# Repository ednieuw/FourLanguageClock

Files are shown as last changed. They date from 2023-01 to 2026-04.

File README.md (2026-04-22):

<h1>&nbsp;SK6812 Four languages word clock</h1>
<p>With this clock time can be displayed as text in the languages Dutch, 
French, English and German.<br>
This clock was the ultimate challenge to make 
with its predecessor a single language word clock and Fibonacci clocks.<br>
	The software to control the clock is written for Arduino with a minimum memory of 
48K such as the cheap Arduino Nano Every.<br>
	
(Update Apr 2026) For the Arduino Nano ESP32 use ESP32_WordclockV202 from this repository.<br>
[For the manual and latest versions see here](https://github.com/ednieuw/Arduino-ESP32-Nano-Wordclock)
	
In addition to controlling the correct time, there are many options that can be set in the program.<br>For 
example, a single language for a clock with 144 (12x12) LEDs, various membrane 
keypads, a rotary, digital displays, a DCF77 atomic time receiver, Bluetooth 
connection to a mobile phone, and support for SK6812 and other LED strips.</p>
<p >&nbsp;</p>
<table>
  <tr><td><a href="4LanguageClock/IMG_5557.JPG">
	<img src="4LanguageClock/IMG_5557k.JPG" alt="Four language clock color" "></a></td><td>
	<a href="4LanguageClock/IMG_5560.JPG">
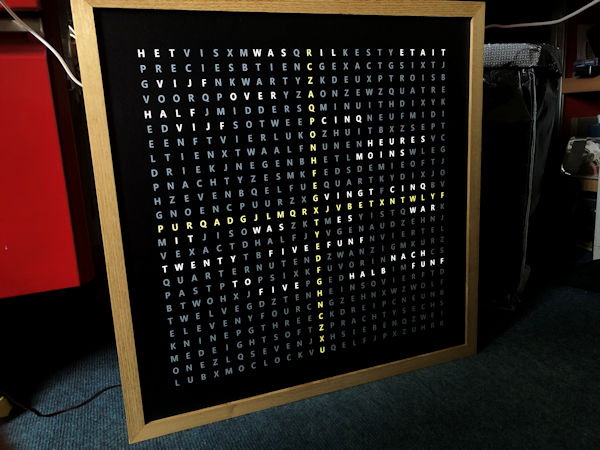
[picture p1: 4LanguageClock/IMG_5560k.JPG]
Four language clock white
	</a></td>
</tr><tr><td>
<br>
<p>&nbsp;</p>
<p>The four-language word clock uses 625 SK6812 RGBW LED strips.<br>RGBW 
LED strips have a white LED in addition to the red, green and blue LED.<br>
This makes it possible to make the letters light up bright white. The 
colors are also sparkling with these SK6812 LEDs.<br>The library used to 
drive the LEDs also supports the use of many types of other LEDs.<br>
<br><br>SK6812 LEDs each contain a small processor, which means that the 
entire chain of LEDs can be controlled with one wire.</p>
</td><td><div align="left">
<a href="4LanguageClock/4-talenklok_IMG_1176.jpg">
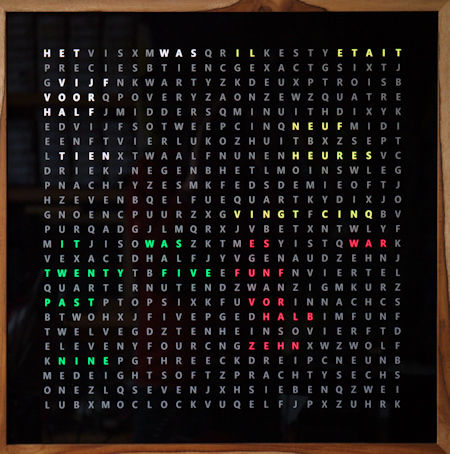
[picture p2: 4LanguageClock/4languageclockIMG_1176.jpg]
Word clock with four languages
</a></div></td></tr>
</table>
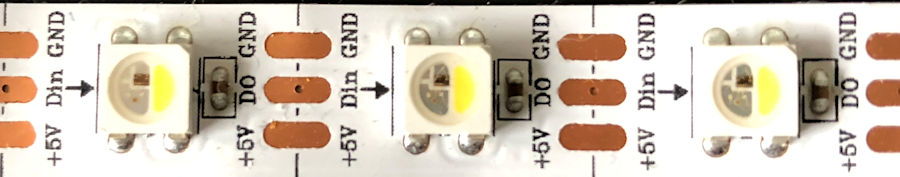
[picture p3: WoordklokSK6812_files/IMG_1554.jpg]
<p>&nbsp;&lt;- <a href="https://ednieuw.nl/Woordklok/index.html">Overview home page<br></a><br><br>
<br>

<br ><span><strong>Accessories</strong></span><br>
The color word clock consists of the parts as shown in the table below.<br>
<table cellspacing="0">
  <tr>
    <td class="xl67" width="277">1 x case for 50x50 cm word plate </td>
    <td class="xl74" width="136">kast </td>
  </tr>
  <tr>
    <td class="xl70">1 x word plate <br>
      JPG-file with:<br>
<a href="4LanguageClock/Viertalen-AlleLetters-23okt2018_50x50cm.jpg">All 625 characters</a><br>
	      <br>
          <a href="4LanguageClock/Viertalen-23okt2018_50x50cm.jpg">With a cross</a></td>
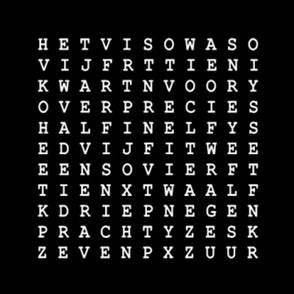
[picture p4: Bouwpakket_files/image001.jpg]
woordplaat
    <td class="xl75">  </td>
  </tr>
  <tr>
    <td class="xl71">1 x Spacerplaat, foamed PVC wit 10 MM RAL 9003</td>
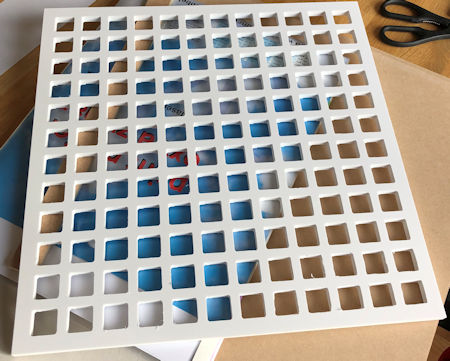
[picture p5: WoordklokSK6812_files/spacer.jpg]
spacerplaat
    <td class="xl76"> </td>
  </tr>
  <tr>
    <td class="xl70">1 x PCB SK6812-klok </td>
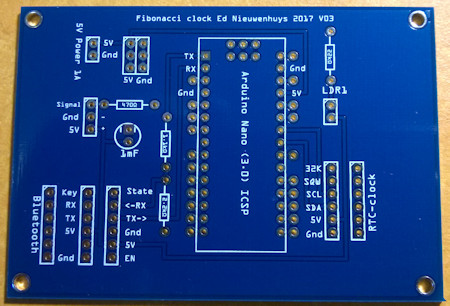
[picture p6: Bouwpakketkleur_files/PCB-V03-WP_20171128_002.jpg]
PCB
    <td class="xl75"> </td>
  </tr>
  <tr>
    <td class="xl70">1 x 1000 µF capacitor </td>
    <td class="xl75">1000 µF condensator </td>
  </tr>
  <tr>
    <td class="xl70">1 x 1.1kΩ resistor </td>
    <td class="xl75">&nbsp; </td>
  </tr>
  <tr>
    <td class="xl70">1 x 2.2kΩ resistor </td>
    <td class="xl75">&nbsp; </td>
  </tr>
  <tr>
    <td class="xl70">1 x 470kΩ resistor (1-3 needed) </td>
    <td class="xl75">470O weerstand </td>
  </tr>
  <tr>
    <td class="xl70">1 x LED red </td>
    <td class="xl75"> </td>
  </tr>
  <tr>
    <td class="xl70">1 x LED yellow </td>
    <td class="xl75"> </td>
  </tr>
  <tr>
    <td class="xl70">1 x 2-pin female connector </td>
    <td class="xl75">&nbsp; </td>
  </tr>
  <tr>
    <td class="xl70">1 x 3-pin female connector </td>
    <td class="xl75">&nbsp; </td>
  </tr>
  <tr>
    <td class="xl70">1 x 5-pin female connector </td>
    <td class="xl75">&nbsp; </td>
  </tr>
  <tr>
    <td class="xl70">2 x 6-pin female connector </td>
    <td class="xl75">&nbsp; </td>
  </tr>
  <tr>
    <td class="xl70">2 x 15-pin female connector </td>
    <td class="xl75">&nbsp; </td>
  </tr>
  <tr>
    <td class="xl70">1 x Arduino Nano Every </td>
    <td class="xl75">&nbsp; </td>
  </tr>
  <tr>
    <td class="xl70">1 x SK6812 LED-strip 625 LEDs </td>
    <td class="xl75">WS2812 </td>
  </tr>
  <tr>
    <td class="xl67">1 x&nbsp; KY-040 Keyes Rotary Encoder </td>
    <td class="xl74">KY-040 Keyes Rotary Encoder </td>
  </tr>
  <tr>
    <td class="xl70">1 x 4x3 membrane keypad </td>
    <td class="xl75">
      <p>&nbsp;</p>
      <p>&nbsp;</p>
      <p>&nbsp;</p></td>
  </tr>
  <tr>
    <td class="xl70">1 x RCT DS3231 clock module <br>
      ZS-042 </td>
    <td class="xl75">DS3231 </td>
  </tr>
  <tr>
    <td class="xl70">1 x CR 2032 3V lithium battery </td>
    <td class="xl75">Batterij </td>
  </tr>
  <tr>
    <td class="xl70">1 x light sensor </td>
    <td class="xl75">Lichtsensor </td>
  </tr>
  <tr>
    <td class="xl71">1 x 22kΩ resistor </td>
    <td class="xl76">22kO weerstand </td>
  </tr>
  <tr>
    <td class="xl70">1 x Adapter 5V DC, &gt;2 Ampere </td>
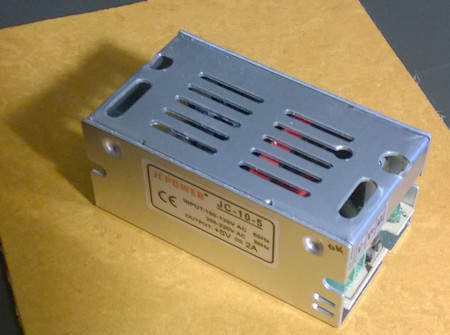
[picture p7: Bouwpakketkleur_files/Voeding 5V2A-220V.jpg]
Voeding220V
    <td class="xl75"> </td>
  </tr>
  <tr>
    <td class="xl67">1 x Verlichtingsgrondplaat 3 x 300 x 300 mm MDF-plaat </td>
    <td class="xl74">&nbsp; </td>
  </tr>
  <tr>
    <td class="xl70">1 x Adapter 5V DC, &gt;2 Ampere </td>
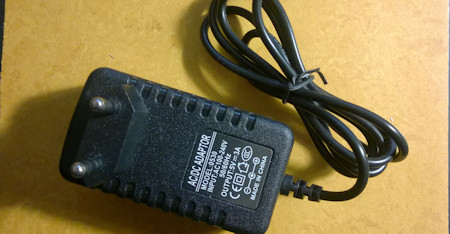
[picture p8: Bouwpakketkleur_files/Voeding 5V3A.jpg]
Voeding
    <td class="xl91"> </td>
  </tr>
  <tr>
    <td class="xl67">Wireless Serial 6 Pin Bluetooth RF Transceiver Module HM10 (voor Iphone, IPad) </td>
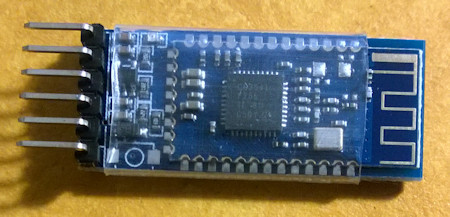
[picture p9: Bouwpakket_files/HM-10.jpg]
HM10 BT
    <td class="xl74"> </td>
  </tr>
</table>
<p class="auto-style3"><strong><br class="auto-style3">
    Assembling the lighting base plate <br class="auto-style3">
  <br class="auto-style3">
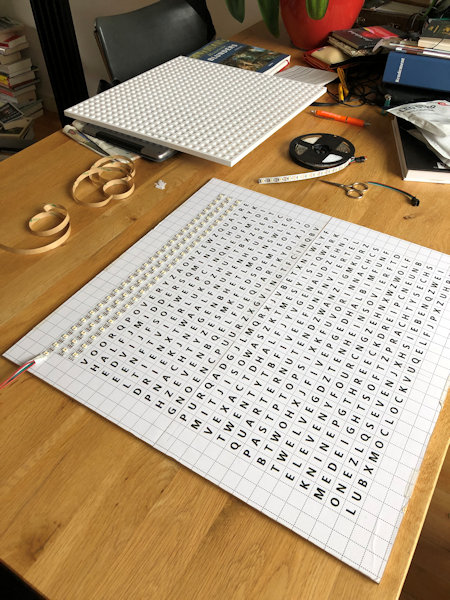
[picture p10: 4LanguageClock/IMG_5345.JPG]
Verlichtings grondplaat
  <br class="auto-style3">
</strong><br class="auto-style3">
</p>
<p>The distance between the LEDs on the strip is suitable to make a clock of 50 
x 50 cm (60 LEDs/m).<br>You can choose to stick the 625 LEDs of the clock in 25 
rows with 25 LEDs or only LEDs behind the letters that should light up.<br>The 
latter method has the advantage that fewer LEDs are needed and that you have to 
drill fewer holes in the spacer plate. But .. there are many more soldering 
points, each of which can cause malfunctions.<br>The software also has a digital 
time mode mode that you can only use if you install all 625 LEDs.<br><br>You can also 
choose to cut out the illuminated words in a 1 cm thick MDF board with a jigsaw.<br>
Paint the insides white otherwise the white light will become dingy.<br>Stick 
the strips from left to right on the odd lines and from right to left on the 
even lines. Follow the arrows on the strip.<span class="auto-style3"><br></p>
<p>Apply solder to the LED strip terminal and later solder the wire in the 
solder blob.<br>A reasonable amount of current (1A) will flow at full 
load. If you are going to connect all the strips in succession, a lot of current 
will flow at the first LEDs and the wire must be thick.<br>I make a connection 
per two lines from the power wire with 30AWG = 0.25mm diameter.<br>30AWG wire 
can tolerate 0.9A current<br>or not insulated tinned copper wire of 0.6mm on one 
side of the strips the 5V connection and on the other side the earth connection.<br>
Finally, make sure that each strip has its power.<br>The spacer plate will be 
placed on the front, on top of the LEDs, and it must lie flat on the surface to 
prevent light leakage.</p>
<table><tr><font face="Verdana, Arial, Helvetica, sans-serif"><td>
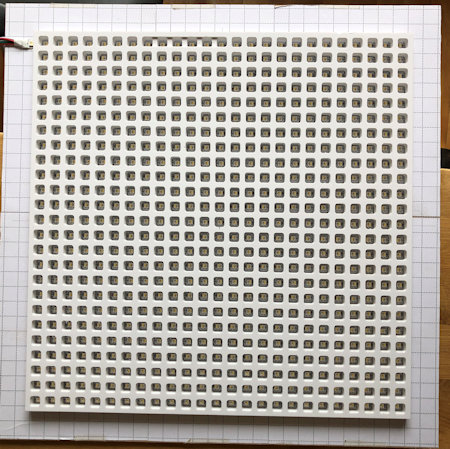
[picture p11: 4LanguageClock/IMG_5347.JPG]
Spacerplaat
 </td>
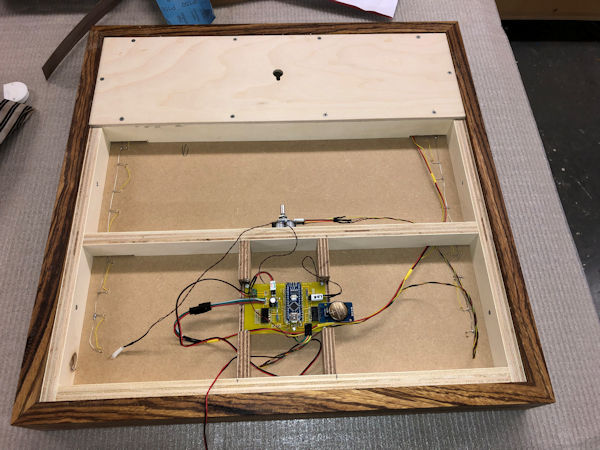
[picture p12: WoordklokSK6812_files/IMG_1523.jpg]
<td></td> 
</font></tr><tr><td>spacer plate</td><td">
Back side</td></tr></table><br">
<p>In the signal wire between LED_PIN 5 (D5) of the Arduino and the SK6812 LED 
connection Di is a 470 Ohm resistor.<br>A 1 mF (1000 uF) capacitor is placed 
across the GND and 5V to the LED strip to dampen the turn-on voltage.<br>The 
LEDs do work without these two components (onrush preventer) but can be damaged.<br>
The onrush preventer schedule is below.<br>You can connect all components 
directly to the pins of the Arduino Nano without the printed circuit board.<br>
There is also a PCB to which everything can be soldered.<br>This printed circuit 
board can also be used for the <a href="https://github.com/ednieuw/Fibonacciclock">Fibonacci clock</a>.<br>
</p>
<p>At the bottom of this page 
the latest PCB version with more connections.</p>
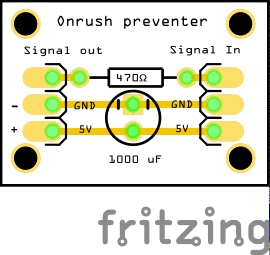
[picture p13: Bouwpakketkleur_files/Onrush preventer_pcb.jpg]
Onrush
<table><tr><td></td>
<td>PCB V03</td>
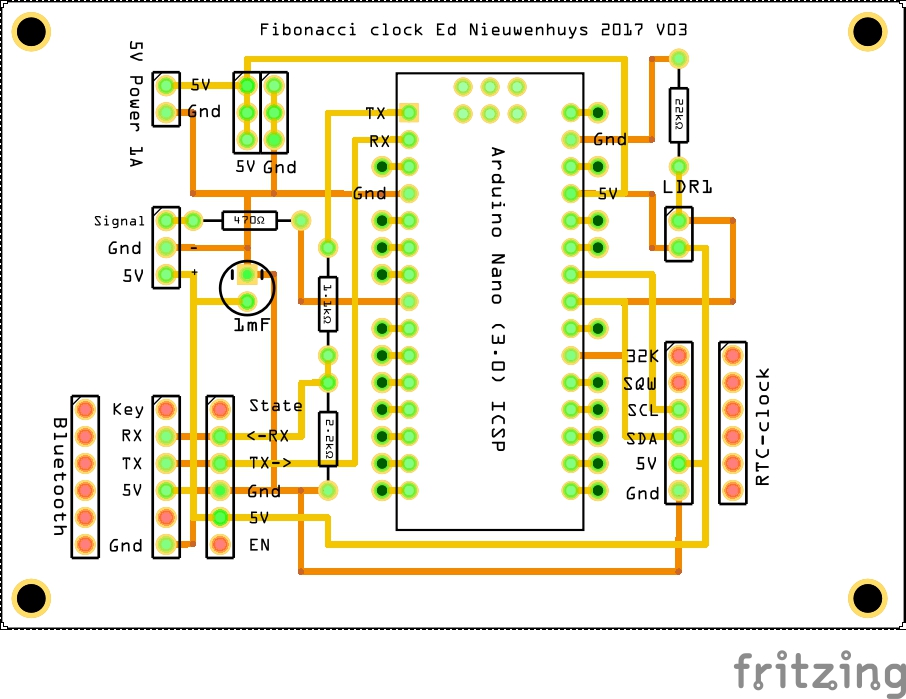
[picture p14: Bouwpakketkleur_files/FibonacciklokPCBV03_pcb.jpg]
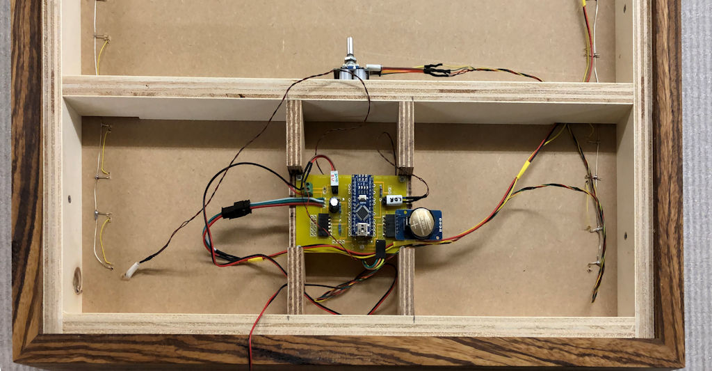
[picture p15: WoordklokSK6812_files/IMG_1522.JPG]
</tr><tr><td colspan="2"><br class="auto-style3"></td></tr><tr><td colspan="2"></td>
</tr><tr><td>
	Connections in the case</td><td class="auto-style3">&nbsp;
	</td></tr></table><span class="style1"><br>// digitale port connections on Arduino&nbsp; D2 - D13<br>
	</span>
<pre>enum DigitalPinAssignments {      // Digital hardware constants ATMEGA 328 ----
 RX           = 0,                // Connects to Bluetooth TX
 TX           = 1,                // Connects to Bluetooth RX
 DCF_PIN      = 2,                // DCFPulse on interrupt  pin
 encoderPinA  = 3,                // right (labeled DT on decoder)on interrupt  pin
 clearButton  = 4,                // switch (labeled SW on decoder)
 LED_PIN      = 5,                // Pin to control colour SK6812/WS2812 LEDs
 BT_TX        = 6,                // Connects to Bluetooth RX
 BT_RX        = 7,                // Connects to Bluetooth TX
 HC_12TX      = 6,                // HC-12 TX Pin  // note RX and TX are reversed compared with a BT Module
 HC_12RX      = 7,                // HC-12 RX Pin 
 encoderPinB  = 8,                // left (labeled CLK on decoder)no interrupt pin  
 secondsPin   = 9,
 HeartbeatLED = 10,               // PIN10        = 10,                        // PIN 10 
 DCFgood      = 11,               // DCF-signal &gt; 50    //PIN11        = 11,   // PIN 11
 PIN12        = 12,               // PIN 12             // led = 12,          // MKR1010
 DCF_LED_Pin  = 13,               // DCF signal
 };
 
enum AnaloguePinAssignments {     // Analogue hardware constants ----
 EmptyA0      = 0,                // Empty
 EmptyA1      = 1,                // Empty
 PhotoCellPin = 2,                // LDR pin
 EmptyA3      = 3,                // Empty
 SDA_pin      = 4,                // SDA pin
 SCL_pin      = 5,                // SCL pin
 EmptyA6     =  6,                // Empty
 EmptyA7     =  7};               // Empty</pre>
<span class="style2">&nbsp;</span><p><strong>Assembling the clock</strong><br>
<br>It is convenient to tape the clock parts with paper masking tape. This 
adhesive tape comes off easily.<br>Stick the lighting plate and spacer together.<br>
Stick a white sheet of paper over the spacer. Paper gives a nice drawing to the 
illuminated letters.<br>Place the word plate over the paper and fix it with 
adhesive tape as well.<br>With a hardwood clock, depending on the version, the 
word plate is slid into the slot in the cabinet. Then assemble the fourth, 
bottom part of the cabinet.<br>Glue this or stick it temporarily with adhesive 
tape.<br>If everything is labeled correctly, the clock, rotary encoder, LDR, 
power supply can be connected.<br>Assemble the cabinet.</p>
<p><br><br></p>
<p><strong>Bluetooth connection</strong><br><br>A Bluetooth connection to the clock can be made 
with the HC05 or HM-10 Bluetooth module.<br>The HC05 only communicates with 
Android. The HM-10 communicates with both Android and Apple IOS.<br>The link 
below describes to which pins the module is connected and how the name of the 
module is changed.<br>With a Bluetooth terminal app on the phone, the time can 
be sent to the clock as hhmmss or hhmm.<br>The clock sends data back to the 
terminal app every minute.<br>Bluetooth terminal apps are available for Windows 
phone, Android and 
<a href="https://apps.apple.com/tt/app/bleserial-hm-10/id1602239700#?platform=iphone">
IPhone</a>.<br>The Bluetooth terminal programs are also available 
for PCs.<br>The Bluetooth module communicates between RX (read) and TX 
(transmit) at 3.3V.<br>It is possible to connect it directly to the Arduino 
ports but it will extend the life of the module if the voltage is lowered to 
3.3V.<br>This can be done with a 3.3V-5V TTL Level Logic Level Converter module, 
or with a voltage divider circuit with resistors as shown below.<br>You can also 
mount the resistors in the wiring from the module to the printed circuit board.</p>
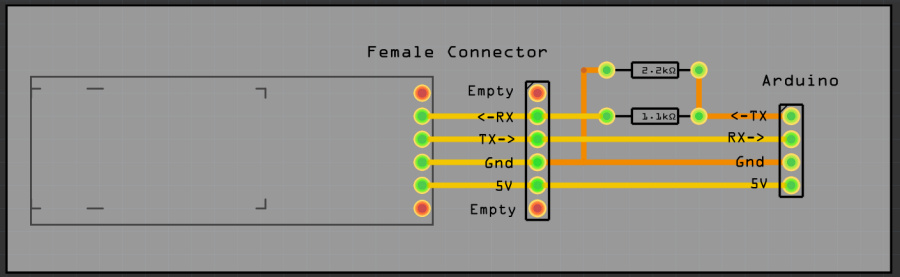
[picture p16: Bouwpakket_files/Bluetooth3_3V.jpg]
Schema BT
<p><font class="auto-style3"><br><br><br>
</font><br></p>
<p><strong>Bluetooth with the HM10 BLE for Android and Apple IOS</strong><br>
With this HM10 BLE module you can communicate with Apple IOS and Android.<br>After that, commands can be sent 
with a serial terminal program (<a href="https://apps.apple.com/tt/app/bleserial-hm-10/id1602239700#?platform=iphone">BLEserial HM-10 for IOS 
</a>or for Android BLE 
scanner from Blue Pixel Technologies) and the clock output can be collected.<br>
<br>Linked via an FTDI, AT commands can be given with the Arduino serial monitor 
with the Bluetooth module.<br>See previous section for AT commands<br>
AT+NAMEnewname gives the module the name: newname</p>
<p><a href="https://ednieuw.nl/BLESerial/BLESerialUsage.html">More info about Bluetooth 
communication on this page</a></p>
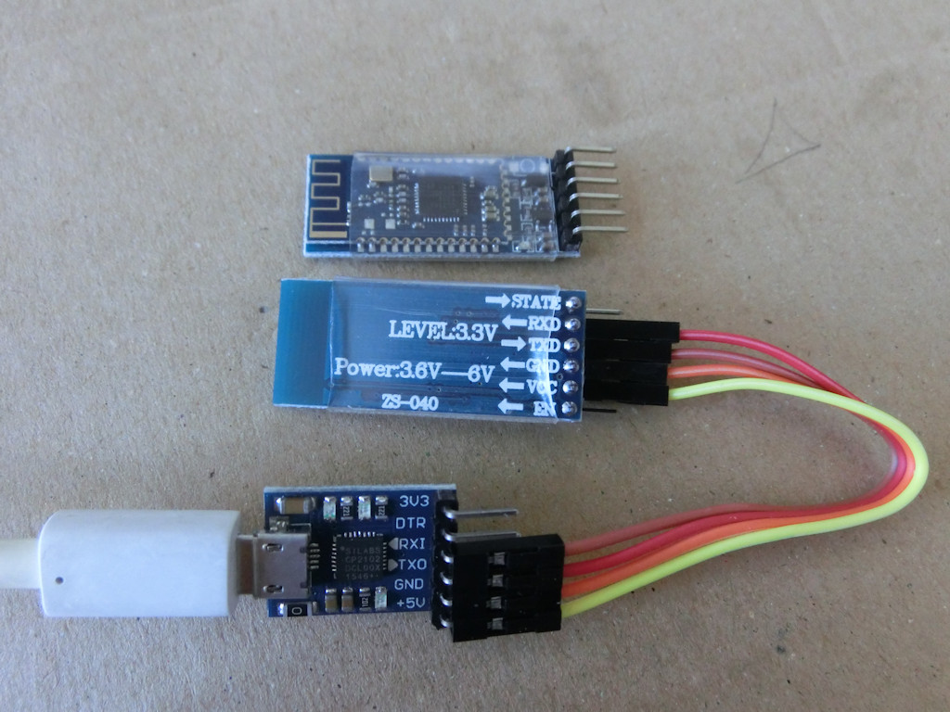
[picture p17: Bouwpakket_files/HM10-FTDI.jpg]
HM-10 BT
<p><font><br><br>
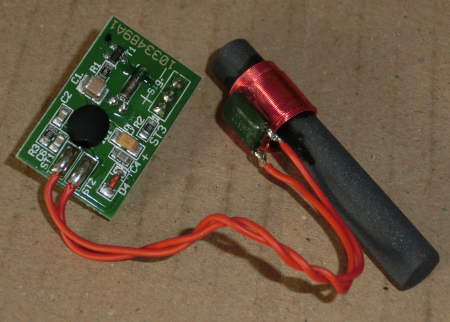
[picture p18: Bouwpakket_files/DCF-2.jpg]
DCF-2
<br><strong>DCF77-ontvangst met DCF-2 module </strong><br><br><br>
</font></p>
<p>Unfortunately, the ICs in the color LEDs interfere with DCF reception. With 
the SK6812 LEDs the interference seems less than with WS2812 color LEDs.<br>With 
these color LEDs, the DCF receiver module must be mounted 10 cm or more from the 
LEDs.<br>The latest software versions V058 and above combine two reception 
methods;<br>the Arduino standard DCF77 library and an interrupt free method 
written by me.<br>I have combined them in the software, which increases 
efficiency by more than 50% in the event of poor reception.<br>Of the 44,000 
minute receptions, with the ferrite rod hanging 7cm from WS2812 color LEDs, 
13,000 were properly processed to a time and date by the DCF77 library and 
22,000 by the interrupt-free routine.<br>This DCF77 module has three 
connections; +, - and signal.<br>Connect the + to 5V and the - to GND.<br>Signal 
goes to pin 2.<br>NB Pin 2 was used for the rotary encoderPinB left (labeled CLK 
on decoder). This is now connected to P8.<br>(Pin 2 is an interrupt pin. For 
optimal DCF reception, responding to an interrupt is not necessary for the 
rotary encoder.<br>Look in the source of the version of the software under "PIN 
Assigments" for the correct connection.</p>
<p><font class="auto-style3"><br><a href="https://ednieuw.nl/Woordklok/DCF77/DCF77_Arduino.html">Here some 
background information DCF</a></font></p>
<p>&nbsp;</p>
<p class="auto-style3"><a href="Libraries-needed-for-ColourClock.zip">Libraries needed</a> 
in this zip-file the needed libraries.<br>
</p><p class="auto-style3"><strong>Software<br></strong></p>
<p>The libraries used can be found in the Arduino IDE.<br>If that is no longer 
the case, the urls to the library have been put below</p>
<pre>
#include "RTClib.h"              // https://github.com/adafruit/RTClib 
#include &lt;TimeLib.h&gt;             // For time management 
#include &lt;Adafruit_NeoPixel.h&gt;   // https://github.com/adafruit/Adafruit_NeoPixel 
#include &lt;SoftwareSerial.h&gt;      // For Bluetooth
#include &lt;Encoder.h&gt;             // http://www.pjrc.com/teensy/td_libs_Encoder.html                      
#include "DCF77.h"               // http://playground.arduino.cc/Code/DCF77 </pre>
<p class="auto-style2"><font class="auto-style3">
<strong>PCB V14</strong><br></font>The latest PCB versions
<span class="auto-style3"> 
<a href="WoordklokSK6812_files/Colour%20Word%20Clock%20PCBV14.fzz">V14</a>
</span>&nbsp;of the PCB have fixed connections for the most commonly used parts.<br>
It is now possible to choose whether the serial connection to the Bluetooth 
module is via the standard connections<br>0 and 1, TX and RX, or whether it goes 
through terminals D6 and D7.<br>In the current version, D6 and D7 are used for 
the Bluetooth module and the pads at D6 and D7 must be soldered closed.<br>The 
signal wire in V14 to the LEDs has been moved relative to V13 so that the 
position of the connections corresponds to the LED strip.</p>
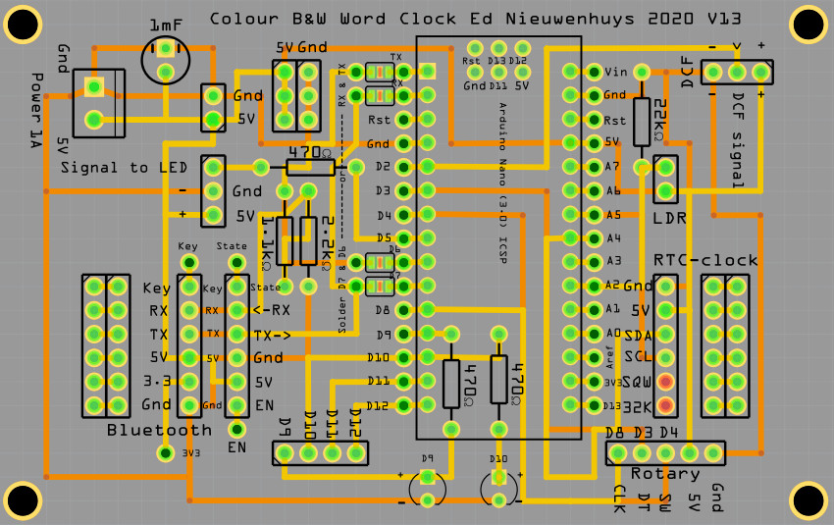
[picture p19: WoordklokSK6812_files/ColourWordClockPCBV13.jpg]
PCB versie V14
<br>&nbsp;<br>
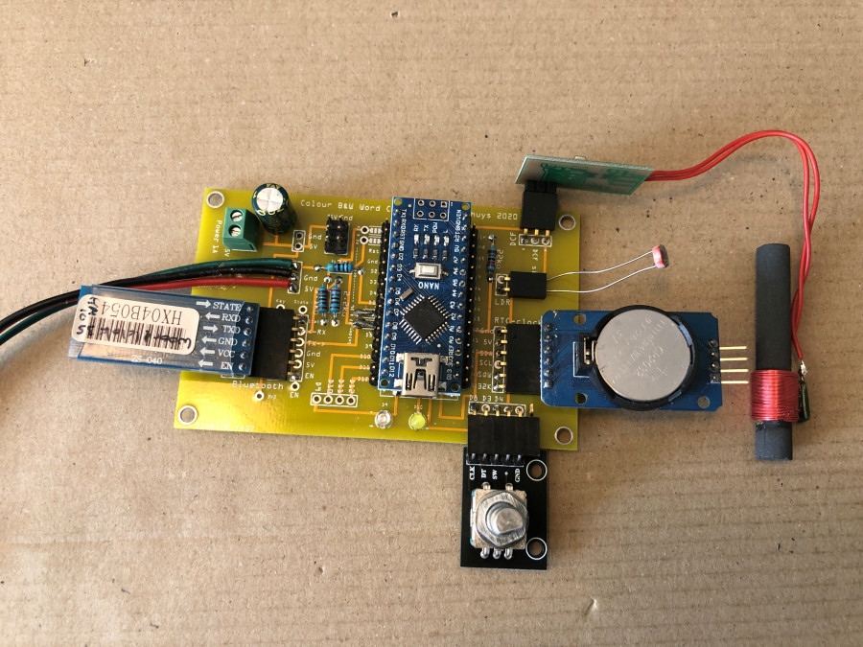
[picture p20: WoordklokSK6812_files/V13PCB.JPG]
PCB V13
<br>
<br class="auto-style3">
<p class="auto-style2"><font class="auto-style3">
</font></p>

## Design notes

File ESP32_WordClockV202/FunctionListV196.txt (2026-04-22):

void setup()                                                                                // ARDUINO Setup.
void loop()                                                                                 // ARDUINO Loop.
void CheckDevices(void)                                                                     // COMMON Check connected input devices.
void EverySecondCheck(void)                                                                 // COMMON Update routine.
void Every100mSecCheck(void)                                                                // COMMON Update routine.
void EveryMinuteUpdate(void)                                                                // COMMON Update routine done every minute.
void EveryHourUpdate(void)                                                                  // COMMON Update routine done every hour.
void EveryDayUpdate(void)                                                                   // COMMON Update routine done every day.
void UpdateStatusLEDs(bool Toggle)                                                          // COMMON Update routine for the status LEDs.
void SetStatusLED(int Red, int Green, int Blue)                                             // COMMON Control the RGB LEDs on the Nano ESP32.
void SetNanoLED13(int intensity)                                                            // COMMON Control orange LED D13 on the Arduino.
void SetPCBLED09(int intensity)                                                             // COMMON Control the RGB LED on the PCB.
void SetPCBLED10(int intensity)                                                             // COMMON Control the RGB LED on the PCB.
void SerialCheck(void)                                                                      // COMMON check for serial input.
void Reset(void)                                                                            // COMMON Reset to default settings. BLE On, WIFI NTP Off.
void ResetCredentials(void)                                                                 // COMMON Reset to empty credential settings WIFI, NTP, BLE ON.
void Tekstprint(char const *tekst)                                                          // COMMON common print routines.
void Tekstprintln(char const *tekst)                                                        // COMMON common print routines.
void TekstSprint(char const *tekst)                                                         // COMMON common print routines.
void TekstSprintln(char const *tekst)                                                       // COMMON common print routines.
void Tekstprintf(const char* fmt, ...)                                                      // COMMON Formatted Tekst print.
void Tekstprintlnf(const char* fmt, ...)                                                    // COMMON Formatted Tekstprintln.
void WTekstappend(char const *tekst, char const *prefix, char const *suffix, bool newline)  // COMMON Print web menu page and BLE menu.
void WTekstprintln(char const *tekst)                                                       // COMMON Print web menu page and BLE menu.
void WTekstprintln(char const *tekst, char const *prefix, char const *suffix)               // COMMON Print web menu page and BLE menu.
void WTekstprint(char const *tekst)                                                         // COMMON Print web menu page and BLE menu.
void WTekstprint(char const *tekst, char const *prefix, char const *suffix)                 // COMMON Print web menu page and BLE menu.
int SConstrainInt(String s,byte first,byte last,int low,int up)                             // COMMON Constrain a string with integers.
int SConstrainInt(String s,byte first,          int low,int up)                             // COMMON Constrain a string with integers.
void InitStorage(void)                                                                      // COMMON Init and check contents of EEPROM.
void StoreStructInFlashMemory(void)                                                         // COMMON Store mem.struct in FlashStorage or SD.
void StoreIRRemoteInFlashMemory(void)                                                       // COMMON Save IR remote settings.
void GetStructFromFlashMemory(void)                                                         // COMMON Get data from FlashStorage.
void GetIRRemoteFromFlashMemory(void)                                                       // COMMON Load IR remote settings from FlashStorage.
void SWversion(void)                                                                        // COMMON Version info.
void SWversion(bool Small)                                                                  // COMMON Version info.
void PrintLine(byte Lengte)                                                                 // COMMON Print a _ line of n length.
void ReworkInputString(String InputString)                                                  // COMMON Input from Bluetooth, Serial or HTML page.
void PrintDisplayChoice()                                                                   // COMMON Print Display choice.
void PrintDisplayChoice(bool PrintIt)                                                       // COMMON Print Display choice.
void PrintTimeInputMethod(byte Im)                                                          // COMMON Print time input method.
void PrintMem(void)                                                                         // COMMON Print permanent Mem memory.
void StoredStartHeaps()                                                                     // COMMON Print memory space.
void StoredStartHeaps(bool Store)                                                           // COMMON Print memory space.
void PrintHeaps(void)                                                                       // COMMON Print memory space.
int ReadLDR(void)                                                                           // COMMON LDR reading are between 0 and 255.
void SetSecondColour(void)                                                                  // CLOCK Set second colour.
void SetColours(void)                                                                       // CLOCK Set second for 4 language clock.
void Selftest(void)                                                                         // CLOCK Set second for 4 language clock.
void Selftest(int Delayms)                                                                  // CLOCK Set second for 4 language clock.
void Displaytime(void)                                                                      // CLOCK Say the time and load the LEDs.
void DimLeds(bool print)                                                                    // CLOCK Dim the leds measured by the LDR and print values.
void Play_Lights()                                                                          // CLOCK Turn On en Off the LED's.
void BlinkUUR(int NoofBlinks, int Delayms)                                                  // CLOCK Turn On en Off the LED's.
void BlinkHETISWAS (int NoofBlinks, int Delayms)                                            // CLOCK Blink ES IST WAR.
void BlinkTWAALF(int NoofBlinks, int Delayms)                                               // CLOCK Blink ZWOLF.
void BlinkUUR(int NoofBlinks, int Delayms)                                                  // CLOCK Blink UUR.
void BlinkHETISWAS (int NoofBlinks, int Delayms)                                            // CLOCK Blink HET IS WAS.
void BlinkTWAALF(int NoofBlinks, int Delayms)                                               // CLOCK Blink TWAALF.
void ColorLeds(char const *Tekst, int FirstLed, int LastLed, uint32_t RGBWColor)            // LED Set color for LEDs in strip and print tekst.
void ColorLed(int Lednr, uint32_t RGBWColor)                                                // LED Set color for LEDs in strip and print tekst.
void LedsOff(void)                                                                          // LED Clear display settings of the LEDs.
void Laatzien(int Delaymsec)                                                                // LED Turn On and the LEDs off after Delaymsec milliseconds.
void ShowLeds(void)                                                                         // LED Push data in LED strip to commit the changes.
void SetBrightnessLeds(byte Bright)                                                         // LED Set brighness of LEDs.
void Stripfill(uint32_t RGBWColor, int FirstLed, int NoofLEDs)                              // LED Set brighness of LEDs.
uint32_t StripGetPixelColor(int Lednr)                                                      // LED Set brighness of LEDs.
void LEDstartup(uint32_t LEDColour)                                                         // LED Synchronize the colour of the LEDstrip with the Status LED.
uint32_t HSVToRGB(double H, double S, double V)                                             // LED convert HSV to RGB  h is from 0-360, s,v values are 0-1.
uint32_t FuncCRGBW( uint32_t Red, uint32_t Green, uint32_t Blue, uint32_t White)            // LED function to make RGBW colour.
void ClearScreen(void)                                                                      // DISPLAY Clear the display.
uint32_t Wheel(byte WheelPos)                                                               // DISPLAY Wheel The colours are a transition r - g - b - back to r.
void StartLeds(void)                                                                        // DISPLAY Initialyse the LEDstrip for WS2812 or SK6812 LEDs.
void ChangeRandomDisplay(void)                                                              // DISPLAY change display choice.
void RainbowCycle(uint8_t wait)                                                             // DISPLAY RainbowCycle.
void WhiteOverRainbow(uint32_t wait, uint8_t whiteSpeed, uint32_t whiteLength )             // DISPLAY WhiteOverRainbow.
void Zet_Pixel(byte Cijfer,byte Pos_X, byte Pos_Y)                                          // DISPLAY Place digits 0 - 9 in Matrix display.
void TimePlaceDigit(byte uur, byte minuut)                                                  // DISPLAY Time in four digits in display.
void WriteLightReducer(int amount)                                                          // CLOCK In- or decrease light intensity value i.e. Slope.
void InitTimeSystem(void)                                                                   // TIME Initialize time system (DS3231 + NTP + internal RTC).
void SetSystemTimeToCompileTime(void)                                                       // TIME Set system time to compile time using basic functions.
time_t GetTijd(bool printit)                                                                // TIME Get current time from best available source.
DateTime GetLocalDateTime()                                                                 // NTP Return local time as RTClib DateTime.
bool GetNTPtime(bool printit)                                                               // NTP print the NTP time for the timezone set.
bool IsDS3231I2Cconnected(void)                                                             // DS3231 check for I2C connection.
float GetDS3231Temp(void)                                                                   // DS3231 temperature.
void SetDS3231Time(void)                                                                    // DS3231 RTC ESP32 -> DS3231.
void GetDS3231Time(bool printit)                                                            // DS3231 reads time in module DS3231.
void PrintTimeHMS()                                                                         // RTC Fill sptext with time.
void PrintTimeHMS(byte format)                                                              // RTC Fill sptext with time.
void SetRTCTime(void)                                                                       // RTC Set time in ESP32 using global timeinfo struct.
void SetSystemTime(time_t t)                                                                // RTC Set RTC time using Unix timestamp.
void PrintAllClockTimes(void)                                                               // CLOCK Print all the times available.
uint32_t HexToDec(const String& hexString)                                                  // CLOCK Convert Hex to uint32.
void Demomode(void)                                                                         // CLOCK Demo mode.
void FireMode(void)                                                                         // CLOCK Fire display on MATRIX_HEIGHT MATRIX_WIDTH.
uint8_t clamp_sub(uint8_t val, uint8_t sub)                                                 // FIRE Utils.
uint8_t clamp_add(uint8_t val, uint8_t add)                                                 // FIRE Utils.
void HeatColor(uint8_t temperature, uint8_t &r, uint8_t &g, uint8_t &b)                     // FIRE Utils.
uint16_t XY(uint8_t x, uint8_t y)                                                           // FIRE Utils.
void Fire2023_2D()                                                                          // FIRE ==== Fire Logic ====.
void Dutch(void)                                                                            // CLOCK Dutch clock display for NL144 & NL92 clock.
void Dutch(void)                                                                            // CLOCK Dutch clock display for NLM1M2M3M4 clock.
void English(void)                                                                          // CLOCK English clock display.
void German(void)                                                                           // CLOCK German clock display.
void French(void)                                                                           // CLOCK French clock display.
void DitLeHeure(void)                                                                       // CLOCK French clock display.
void SendMessageBLE(std::string Message)                                                    // BLE SendMessage by BLE Slow in packets of 20 chars.
void StartBLEService(void)                                                                  // BLE Start BLE Service.
void DisconnectBLE(void)                                                                    // BLE Disconnect BLE Service.
void CheckBLE(void)                                                                         // BLE CheckBLE input and rework string.
void SendMessageTimeReceiver(const char* msg)                                               // BLE TimeReceiver client.
void ReconnectTimeReceiver()                                                                // BLE TimeReceiver Reconnect time receiver.
void StartTimeReceiverScan(void)                                                            // BLE TimeReceiver Start Time Receiver scan.
void StopTimeReceiver()                                                                     // BLE TimeReceiver Stop Time Receiver.
void CheckTimeReceiverClient(void)                                                          // BLE TimeReceiver Check TimeReceiver Client.
void WiFiEvent(WiFiEvent_t event)                                                           // WIFI WIFIEvents.
void ScanWIFI(void)                                                                         // WIFI Scan for WIFI stations and print a list of networks found.
void ConnectWIFI(void)                                                                      // WIFI Check for WIFI router SSID and password.
void CheckRestoreWIFIconnectivity(void)                                                     // WIFI Check if WIFI is still connected and if not restore it.
bool StartWIFI_NTP(void)                                                                    // WIFI Start WIFI connection and NTP service.
void NTPnotify(struct timeval* tv)                                                          // NTP functions.
void CheckandPrintNTPsynced(void)                                                           // NTP functions.
void setTimezone()                                                                          // NTP functions.
void initSNTP()                                                                             // NTP functions.
bool wait4SNTP()                                                                            // NTP Get a NTP time and wait max 2.5 sec.
void CheckWIFIcommand(void)                                                                 // WIFI Check for a Pending command received from the web page.
void WebPage(void)                                                                          // WIFI WEBPAGE.
void notFound(AsyncWebServerRequest *request)                                               // WIFI WEBPAGE.
void StartAPMode(void)                                                                      // WIFI WEBPAGE Login credentials Access Point page with 192.168.4.1.
void wpsInitConfig()                                                                        // WIFI WPS functions.
void wpsStart()                                                                             // WIFI WPS functions.
void wpsStop()                                                                              // WIFI WPS functions.
String wpspin2string(uint8_t a[])                                                           // WIFI WPS functions.
void OnewireKeypad3x4Check(void)                                                            // KEYPAD check for Onewire Keypad input.
void OnewireKeypad3x1Check(void)                                                            // KEYPAD check for Onewire Keypad input with 5V and 1.1, 4.7, 4.7, 4.7 kOhm resistors.
void Keypad3x1Check(void)                                                                   // KEYPAD 3x1 Init.
void RotaryEncoderCheck(void)                                                               // KY-040 ROTARY check if the rotary is moving.
void ProcessKeyPressTurn(int encoderPos)                                                    // CLOCK KY-040 Rotary or Membrane 3x1 processing input.
void Start_IRreceiver(void)                                                                 // IR-RECEIVER Start alarge or tiny IR-RECEIVER.
void Init_IRreceiver(String* ButtonTempNames, byte numButtons)                              // IR-RECEIVER Init.
uint16_t IrReceiverDecode(void)                                                             // IR-RECEIVER Decode received signal,.
void ProcessLearningMode(decode_type_t protocol, uint16_t command, uint16_t address)        // IR-RECEIVER Decode received signal,.
void ProcessRecognitionMode(decode_type_t protocol, uint16_t command, uint16_t address)     // IR-RECEIVER Decode received signal,.
void StartIRLearning(void)                                                                  // IR-RECEIVER Initializes learning mode.
void PrintAllMappings(void)                                                                 // IR-RECEIVER Shows learned buttons.
void ResetAllIRremoteSettings(void)                                                         // IR-RECEIVER Reset all settings.
int RecognizeButton(decode_type_t protocol, uint16_t command, uint16_t address)             // IR-RECEIVER Identifies button pressed.
void ReworkIRremoteValue(int ButtonNamesNr)                                                 // IR-RECEIVER ReworkRemoteValue.
void AdjustTime(int DeltaHours, int DeltaMinutes, int DeltaSeconds)                         // IR-RECEIVER Adjust current time by hours/minutes/seconds.
void ToggleIRpower(void)                                                                    // IR-RECEIVER Turn On or off Remote control.
void InitLogBuffer()                                                                        // LOGBUFFER Initialize circular logging buffer.
void AddLog(const char* msg)                                                                // LOGBUFFER Add a log line (raw C-string). Always ends with '\n'.
void HandleTekstPrint(AsyncWebServerRequest* request)                                       // LOGBUFFER Printlast 500 lines.
void HandleTekstDownload(AsyncWebServerRequest *request)                                    // LOGBUFFER Stream all the circular log buffer directly to the client.

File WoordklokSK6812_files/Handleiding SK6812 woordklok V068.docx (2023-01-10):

# Handleiding SK6812 woordklok V043

Deze woordklok toont de tijd als tekst. De tekst kan als witte tekst maar ook in kleur getoond worden.

Om de tijd en instellingen aan te passen kan de klok met een draaiknop bediend worden.

Behalve met de draaiknop kunnen instellingen met een Bluetooth-verbinding tussen de klok en een telefoon, tablet of PC uitgerust met Bluetooth-BLE ingesteld worden. Als derde optie is een USB-PC-verbinding met een FTDI CP2102 module mogelijk. Deze aansluiting wordt ook gebruikt om de ATMEGA1280 te programmeren.

De klok bevat een klok-module waarin een CR2032 batterij de spanning verzorgt als de klok uit staat. Als de klok zijn tijd niet meer vast houdt na een stroomonderbreking dient de batterij vervangen te worden.

Deze klok is uitgerust met een HM-10 Bluetooth module. Deze kan verbonden worden met een IPhone of een Android telefoon van 2018 of later.

Voor de IPhone dient het programma ….

Voor de Android kan ….

De klok is geprogrammeerd met een Arduino IDE programma versie 1.8.10 voor een ATMEGA1284 chip en met als versie: Character_Colour_Clock_SK6812_1284-MKR1010_V043.

Draaiknop:

Druk op de knop om het keuzemenu te activeren.

Na een druk op de knop gaat de tekst UUR knipperen. Door de draaiknop de draaien kunnen de uren veranderd worden

Een tweede druk op de knop laat de tekst HET IS WAS knipperen. Nu kunnen de minuten gelijk gezet worden.

Een derde druk doet veel tekst oplichten. Nu kan de intensiteit van de klok aangepast worden door aan de knop te draaien

De vierde en volgende drukken doorloopt de diverse kleurschema.

4 Gele tekst. HET geeft van groen via geel tot rood aan hoever het uur gevorderd is. IS en WAS geven dit aan voor de minuut.

5 Elk uur een andere kleur van de tekst. HET, IS en WAS doorlopen weer een uur-minuut verloop

6 Alle tekst in wit.

7 Alle tekst kan een eigen samengestelde kleur aannemen. Door de draaien aan de knop worden alle kleuren van de regenboog doorlopen

8 als hierboven maar HET, IS en WAS doorlopen weer een uur-minuut verloop

9 De keuze toont een digitale klok die handig kan zijn om de tijd precies te zetten

DEFAULTCOLOUR = 0; Yellow text. HET Green to Red hour IS WAS Green to Red Minute

HOURLYCOLOUR = 1; Every hour other colour text. HET Green to Red hour IS WAS Green to Red Minute

WHITECOLOR = 2; All white text

OWNCOLOUR = 3; All own colour

OWNHETISCLR = 4; All own color. HET Green to Red hour IS WAS Green to Red Minute

WHEELCOLOR = 5; Every second another colour of rainbow

DIGITAL = 6; Digital display

Linksom, tegen de klok in, is uren omhoog.

Rechtsom, met de klok mee, in minuten omhoog.

Door op de draaiknop te drukken kan er tussen diverse kleurmogelijkheden gekozen worden.

Jullie klok staat standaard op wit.

Keuze 1 LetterColor = Wit en na een alle opties doorgelopen te zijn geel

Keuze 2 LetterColor = Wit

Keuze 3 LetterColor = elk uur een andere kleur

Keuze 4 LetterColor = Blauw

Keuze 5 LetterColor = Blauw, HET IS WAS bljjft blauw

Keuze 6 LetterColor = ++++++++++++++++++++++++++++++++++++++++++++++++++++++++++++++++++++een langzaam veranderende kleur

Keuze 7 LetterColor = digitaal de tijd in de klok. (Handig om de tijd precies gelijk te zetten)

Ed Nieuwenhuys

ednieuw@xs4all.nl

06 236 10 994

Woordklok nummer 36 en 37, November 2019

C:\Users\ednie\Documents\Files\Handleiding SK6812 woordklok V043.docx

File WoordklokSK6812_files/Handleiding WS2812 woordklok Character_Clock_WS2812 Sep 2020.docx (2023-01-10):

Deze woordklok toont de tijd als tekst.
De tekst kan als witte tekst maar ook in kleur getoond worden. Voor de verlichting zijn WS2812 RGB LEDs gebruikt.

De klok is geprogrammeerd met een Arduino IDE programma versie 1.8.13 of nieuwer voor een Arduino Nano processor en met als softwareversie: Character_Clock_WS2812_Sep2020.
De klok bevat een DS3231 klokmodule waarin een CR2032 batterij de spanning verzorgt als de klok uit staat. Deze klokmodule verloopt slechts enkele seconden per jaar maar voorziet niet in de zomer-wintertijdwissel.
Als de klok zijn tijd niet meer vasthoudt na een stroomonderbreking dient de batterij vervangen te worden.

Deze klok kan zijn uitgerust met een HM-10 BLE Bluetooth-module. Deze kan verbonden worden met een IPhone of een Android telefoon.

Voor de IPhone kan het programma “BLE terminal” gebruikt worden.

Voor de Android kan “Serial Bluetooth van Kai Morich” gebruikt worden.

Om instellingen en tijd aan te passen kan de klok met een draaidrukknop bediend worden.

Behalve met de draaiknop kunnen instellingen met een Bluetooth-verbinding tussen de klok en een telefoon, tablet of PC uitgerust met Bluetooth-BLE ingesteld worden.

De klok onthoud de ingestelde waarden van L, M, P en Q in het menu als de stroom van de klok wordt gehaald. Dit is de minimale en maximale lichtsterkte, eigen kleur en displaykeuze.

Als derde optie om instellingen aan te passen is een USB-PC-verbinding mogelijk. Met de seriële monitor in de Arduino IDE kan de klok bedient worden. Hiervoor dient een USB-mini kabel aan de PC te worden gekoppeld.

De Arduino IDE kan van de Arduino.cc website gedownload

In het programma Arduino IDE kan bij Tools >Port de Arduino Every gevonden worden. Kies een COM-poort waar Nano Every achter staat

Kies Tools->Serial monitor om de monitor te openen.

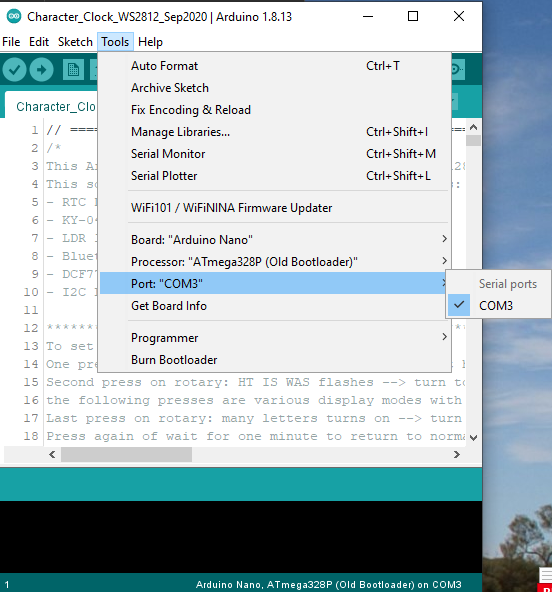
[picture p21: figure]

Met een Bluetooth-verbinding op de telefoon of PC kan hetzelfde gedaan worden.

Als verbinding met de PC wordt gelegd wordt het volgende getoond.

Door de ‘I’ van info in de seriële monitor te krijgen kan het menu weer getoond worden

*********

Serial 9600 baud enabled

Rotary enabled

15:41:49 18-09-2020

____________________________________________________

Rick Degens Woordklok

Voer in:

Tijd uumm (1721) of uummss (172145)

Dddmmjjjj (D15122017 voor 15 December 2017)

Lnn (L5) Min lichtintensiteit ( 1 - 255)

Mnn (M90)Max lichtintensiteit (1% - 250%)

Pnnnnnn (P2345DD) voor eigen RGB-kleur (n=0-F)

Qn (Q2) voor palettekeuze (Q0-4)

Q0 Geel, HET ISWAS verkleurt

Q1 Uurkleur, HET ISWAS verkleurt

Q2 Wit

Q3 Eigen kleur

Q4 Eigen kleur HET ISWAS verkleurt

I info

X Demo mode

Z Zelftest

Ed Nieuwenhuys Character_Clock_WS2812 Sep 2020

____________________________________________________

Brightness Min: 5 bits Max: 55%

LDR read Min: 999 bits Max: 1 bits

Display choice: 2

____________________________________________________

Het is tien over half vier 15:41:49 18-09-2020

LDR:531 (516-531)->100=39% T=21C 15:42:00

Het was tien over half vier 15:42:00 18-09-2020

Als de seriële monitor wordt gebruikt wordt de klok gereset. Je ziet dan welke componenten geïnstalleerd zijn. Met een Bluetooth-verbinding gebeurt dit niet.

Elke 30 seconden wordt een regel geprint

Het is tien over half vier 15:41:49 18-09-2020

LDR:531 (516-531)->100=39% T=21C 15:42:00

Het was tien over half vier 15:42:00 18-09-2020

LDR:532 (516-532)->101=39% T=21C 15:42:30

LDR:532 (516-532)->101=39% T=21C 15:43:00

Het was tien over half vier 15:43:00 18-09-2020

LDR:532 (516-532)->101=39% T=21C 15:43:30


Eerst de lichtsterkte van de lichtsensor; LDR: ( 0 -1024) in bits en daarna omgerekend naar het percentage waarmee de LEDs branden ten opzicht van vol vermogen.
Daarna de temperatuur in de klok.

Draaiknop

Druk op de knop om het keuzemenu te activeren.

Na een druk op de knop gaat de tekst UUR knipperen. Door de draaiknop de draaien kunnen de uren veranderd worden

Een tweede druk op de knop laat de minuten knipperen. Nu kunnen de minuten gelijk gezet worden.

Een derde druk doet veel tekst oplichten. Nu kan de intensiteit van de klok aangepast worden door aan de knop te draaien.

De vierde en volgende drukken doorloopt de diverse kleurschema.

4 Q0 Gele tekst. HET loopt van groen naar rood via geel in een uur. IS en WAS doen dit per minuut

5 Q1 Elk uur een andere kleur van de tekst. HET loopt van groen naar rood via geel in een uur. IS en WAS doen dit per minuut

6 Q2 Alle tekst in wit.

7 Q3 Alle tekst kan een eigen samengestelde kleur aannemen.

Deze samengestelde kleur kan worden gemaakt door in het menu van de klok nadat een verbinding met Bluetooth of de PC is gelegd Prrggbb te tikken. De rr, gg en bb zijn de primaire kleuren. Deze kan de waarde 00 – FF hebben. Dit is een hexadecimale waarde

Dus PFF0000 is knalrood en P0000FF knalblauw. Geel is PFFFF00. Rood en groen geeft geel.

8 Q4 De eigen kleur. HET loopt van groen naar rood via geel in een uur. IS en WAS doen dit per minuut

Menu-opties

Enter time as: hhmm (1321)or hhmmss (132145)

Voer de tijd in als hhmmss.

Bijvoorbeeld 051205 om 5 uur, 12 minuten en 5 seconden in de ochtend in te voeren

D D15122017 is date 15 December 2017

Voer de datum in als Dddmmyyyy.

Lnn (L5) Min light intensity ( 1-255 bits)

Voer de laagste lichtsterkte in bits in door L met een getal van maximaal 255. Bijvoorbeeld: L12

L5 in een redelijke waarde zodat de klok midden in de nacht niet te fel brandt

Mnn (M90)Max light intensity (1%-250%)

Met M en een waarde tussen 1 en 250 kan de lichtsterkte worden ingesteld.

M50 is een goede startwaarde.

Pnnnnnn (P234F8A) own colour (n=0-F)

Je kan een eigen kleur voor de verlichting instellen. Deze wordt als hexadecimale waarde ingevoerd.

De kleuren in de LED zijn RGB, rood, groen, blauw die een waarde tussen 00 en FF (=255) kunnen hebben. De volgorde is Prrggbb

PFF0000 = rood

P0000FF = blauw

P00FF00 = groen

P66CDAA = aquamarine

De klok dimt lichtsterkte door deze RGB-waarde te verkleinen. Bij de kleur aquamarine zal het rood dusals eerste gaan verdwijnen als het donker wordt.
De minimale lichtsterkte ingesteld met de optie Lnn kan kleurverlies voorkomen.

Qn Display Choice (Q0-4)

Q0 = Geel, HET ISWAS verkleurt

Q1 = Uurkleur, HET ISWAS verkleurt

Q2 = Wit

Q3 = Eigen kleur

Q4 = Eigen kleur HET ISWAS verkleurt
Kies het gewenste kleurschema met Q0 – Q7

I For this info

Print het menu door I in te voeren

Xnn (X50) Demo mode. ms delay (0-9999)

Door X in te voeren worden alle kleuren getoond in de letters

Druk X weer in om te stoppen

Z for Self test

Alle LEDs laten een spektakel zien.

De Z weer om te stoppen Dit kan even duren omdat de zelftest ongeveer een minuut duurt.

Of herstart de seriële monitor.

Ed Nieuwenhuys

ednieuw@xs4all.nl

06 236 10 994

C:\Users\ednie\Documents\Files\Handleiding SK6812 Fibonacci-woordklok V061.docx

Handleiding WS2812 Woordklok Sep2020

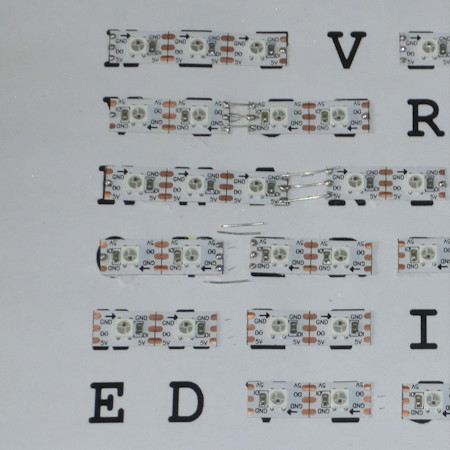
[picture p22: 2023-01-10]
Bouwpakketkleur_files/CIMG2970.JPG

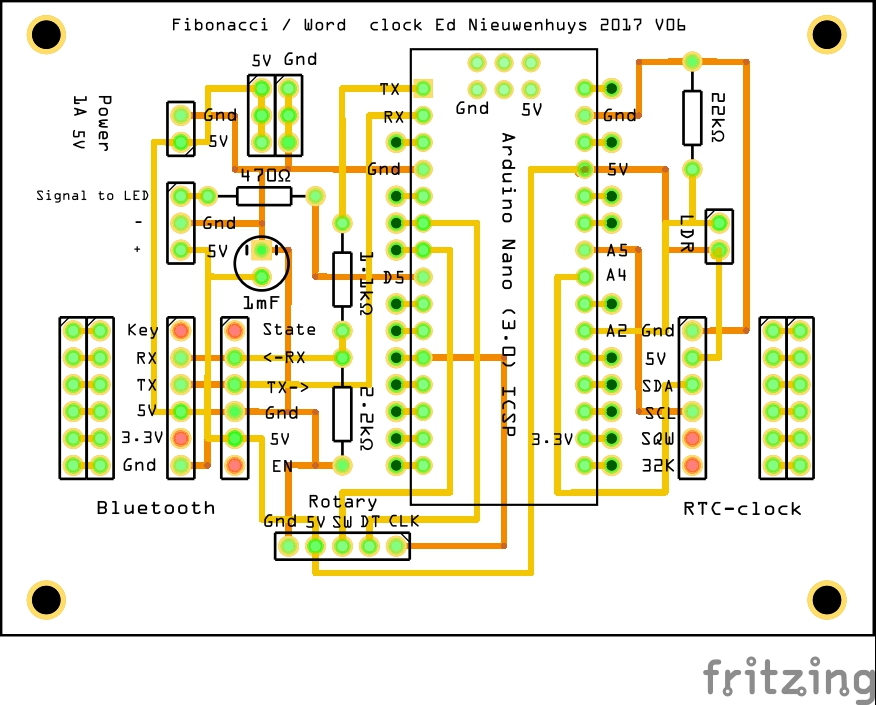
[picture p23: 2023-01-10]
Bouwpakketkleur_files/FibonacciklokPCBV06_pcb.jpg

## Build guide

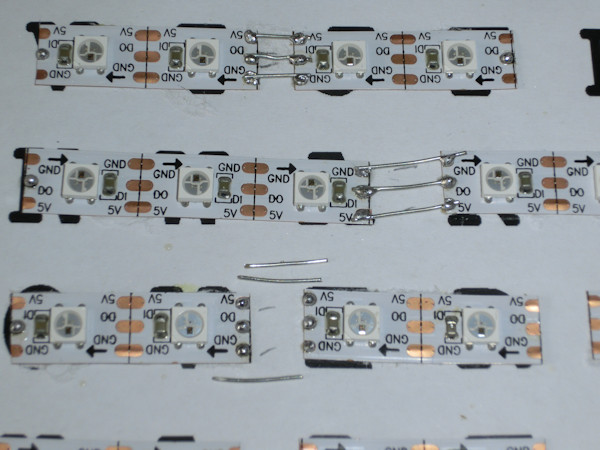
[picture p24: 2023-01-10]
Bouwpakketkleur_files/Solderen-Led-CIMG2971.JPG

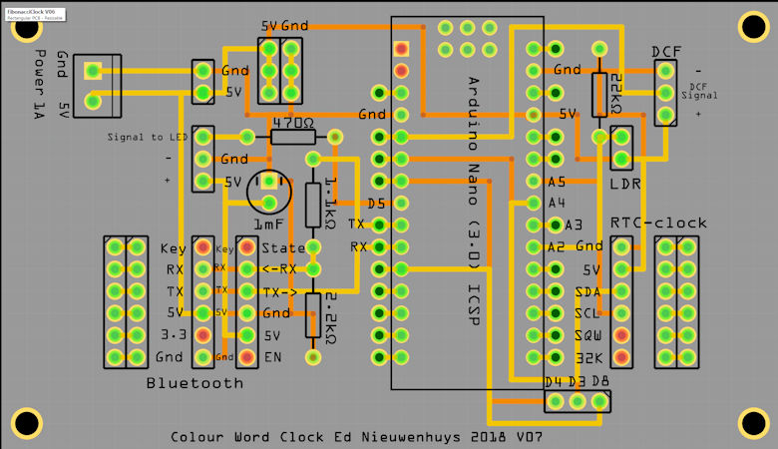
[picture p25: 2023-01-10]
WoordklokSK6812_files/PrintplaatV07.jpg

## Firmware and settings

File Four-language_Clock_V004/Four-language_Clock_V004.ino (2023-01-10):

// =============================================================================================================================
/* 
This Arduino code controls the Nano Every, ATMEGA1284 chip and Arduino MKR1010 that controls the LED strips of the Word Clock
This source contains code for the following modules:  
- RTC DS3231 ZS-042 clock module
- KY-040 Keyes Rotary Encoder
- LDR light sensor 5528
- Bluetooth RF Transceiver Module HC05 and HM10 BLE
- DCF77 module DCF-2
- LCD
- WIFI on MKR 1010 to get NTP time

Load and install in IDE:
http://arduino.esp8266.com/stable/package_esp8266com_index.json  (ESP-12)
https://mcudude.github.io/MightyCore/package_MCUdude_MightyCore_index.json ATMEGA1260 and 644
https://raw.githubusercontent.com/damellis/attiny/ide-1.6.x-boards-manager/package_damellis_attiny_index.json ATTINY
Arduino SAMD for MKR1010

The HC05 or HM-10 Bluetooth module is used to read and write information or instructions to the clock
The DCF77 module can be attached to adjust the time to the second with German longwave time signal received by the module.
The DCFNOINT subroutine is  a non-interrupt driven DCF77 decoding routine. Using both together improves decoding efficiency

Arduino Uno, Nano with SK6812 LEDs: Program size must stay below approx 23572, 1129 bytes bytes with 144 LEDs in ATMEGA 32KB 
With a Arduino Nano Every with 64kb memory this is not a problem
************************************************************************************
To set the time with the rotary button:
One press on rotary: UUR is flashing -> turn to set hour
Second press on rotary: HT IS WAS flashes --> turn to set minute
the following presses are various display modes with the DIGITAL choice as second last 
Last press on rotary: many letters turns on --> turn to set intensity level of the LEDs
Press again of wait for one minute to return to normal operation
Displaymodes (Qn):
DEFAULTCOLOUR = 0; Yellow text.  HET Green to Red hour IS WAS Green to Red Minute  
HOURLYCOLOUR  = 1; Every hour other colour text. HET Green to Red hour IS WAS Green to Red Minute         
WHITECOLOR    = 2; All white text
OWNCOLOUR     = 3; All own colour
OWNHETISCLR   = 4; All own colour. HET Green to Red hour IS WAS Green to Red Minute
WHEELCOLOR    = 5; Every second another colour of rainbow
DIGITAL       = 6; Digital display
************************************************************************************
 Author .: Ed Nieuwenhuys 
 Program name; Four-language Clock_V0xx
 
 Changes.: V001 Adapted from Character_Colour_Clock_V060  Added || Dday>31  SIX ->SIXUK  
 Changes.: V002 Serialcheck in Demomode() and Selftest(). Changed own color entry to Pwwrrggbb instead of Prrggbb
                Counters for DCF Wrong times reported added. LedsOnOff added. sorage in Mem. EEPROM added
                Removed SetMinuteColour() and CheckColourStatus() and fused them in SetSecondColour(). 
                Optimized DCFNOINT code TimeMinutesDiff <2 --> <10.Added EEPROM.put in setup.
                Added || Dday>31 in  updateDCFclock. sizeof(menu) / sizeof(menu[0]). Added PrintLine sub routine
Changes.: V003  Removed Changing color HET IS WAS per second
Changes.: V004  Changed menu operation. Added const ColorLeds(char const *Tekst. Removed compiler warnings
                Dsecond, ..., Dyear --> tmElements_t D time struct
                Isecond, ..., Iyear --> tmElements_t I time struct
                LDR readings stored in NVRAMDS3231
                DCF routines copied from Character_Colour_Clock_V069
                Optimized loop() with function InputDevicesCheck(void)
                Tekstprintln() changed coding
                Made more fault date control in DCFNoInt
                Made GetSecondsSince2000DCFNoInt() more robust when no signal is received
                Main source code comparable with Character_Colour_Clock_V069
 */
// ===============================================================================================================================

//------------------------------------------------------------------------------
// ARDUINO Definition of installed modules
//------------------------------------------------------------------------------
// ------------------>   Define one type of LED strip 
//#define LED2812
#define LED6812                                // Choose between LED type RGB=LED2812 or RGBW=LED6812
// ------------------>   Define which library
//#define NEOPIXEL                             // Adafruit Neopixel
//#define FABLED                               // FABLED alleen UNO en Nano
//#define LIBSK6812                              // SK6812 library. Only with SK6812 LEDs

// ------------------>  Define which module is present.  
#define BLUETOOTHMOD                           // Use  this define if Bluetooth needs other pins than pin 0 and pin 1
//#define HC12MOD                              // Use HC12 time transreceiver Long Range Wireless Communication Module in Bluetooth slot
#define DCF77MOD                               // DCF77 receiver installed
#define MOD_DS3231                             // The DS3231 module is installed, Otherwise the Arduino internal clock is used
//#define LCDMOD                               // LCD installed

#define ROTARYMOD                              // Rotary encoder installed
//#define ONEWIREKEYPAD3x1                     // Use a 3x1 keypad with one wire   
//#define ONEWIREKEYPAD3x4                     // Use a 3x4 keypad with one wire

char VERSION[] = "Four-language Clock_V004";
//------------------------------------------------------------------------------
// ARDUINO Definition of installed language word clock
//------------------------------------------------------------------------------
#define NL
#define UK
#define DE
#define FR        
//------------------------------------------------------------------------------
// ARDUINO Includes defines and initialisations
//------------------------------------------------------------------------------
                     #if defined(ROTARYMOD) || defined(ONEWIREKEYPAD3x1) || defined(ONEWIREKEYPAD3x4)
#define ROTKEYMOD                                  // Make this #ifdef easier to read
                     #endif
                     #if defined(__AVR_ATmega644P__) || defined(__AVR_ATmega644__) || defined(__AVR_ATmega1284P__) || defined(__AVR_ATmega1284__)
#define ATmega644_1284                                    // Make this #ifdef easier to read
                     #endif
                     #ifdef DCF77MOD
#define DCFMOD                                            // Use the Arduino DCF77 library with interrupts. Turning DCF77 off saves 4.4K bytes
#define DCFNOINT                                          // Use the Tiny DCF algorithm in this program.    Turning DCFNOINT off saves 4.0K bytes
                     #endif

#include <Wire.h>                                         // Arduino
#include "RTClib.h"                                       // https://github.com/adafruit/RTClib 
#include <TimeLib.h>                                      // For time management 
//#include <avr/wdt.h>                                    // for reset function
#include <avr/pgmspace.h>                                 // Arduino
                     #ifdef ARDUINO_SAMD_MKRWIFI1010
#include <FlashAsEEPROM.h>                                // url=https://github.com/cmaglie/FlashStorage
#include <SPI.h>                                          // for web server
#include <WiFiNINA.h>                                     // url=http://www.arduino.cc/en/Reference/WiFiNINA 
//#include "arduino_secrets.h"                            // for web server
#define SECRET_SSID "PWDis_klok"
#define SECRET_PASS "klok"
                     #else
#include <EEPROM.h>
                     #endif // ARDUINO_SAMD_MKRWIFI1010
                     #ifdef LCDMOD
#include <LCD.h>
#include <LiquidCrystal_I2C.h>                            // https://bitbucket.org/fmalpartida/new-liquidcrystal/wiki/Home
                     #endif // LCDMOD    
#include <Adafruit_NeoPixel.h>                            // https://github.com/adafruit/Adafruit_NeoPixel 
                     #ifdef HC12MOD
#include <SoftwareSerial.h>                               // For HC12 transceiver
                     #endif //HC12MOD 
//                     #ifdef ATmega644_1284
                     #ifdef BLUETOOTHMOD
#include <SoftwareSerial.h>                               // Arduino library (for Bluetooth communication)
                     #endif //BLUETOOTHMOD
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
void loop()
{
                      InputDevicesCheck();                                                    // Check for input from input devices
 if (Demo)            Demomode();
 else if (Zelftest)   Selftest();   
 else                 EverySecondCheck();  
}
//                                                                                            //
//------------------------------------------------------------------------------
// ARDUINO Setup
//------------------------------------------------------------------------------
void setup()
{                                                            
 Serial.begin(9600);                                                                          // Setup the serial port to 9600 baud  
 while (!Serial);                                                                             // wait for serial port to connect. Needed for native USB port only
 Tekstprintln("\n*********\nSerial started"); 
 Wire.begin();                                                                                // Start communication with I2C / TWI devices     
 pinMode(DCF_LED_Pin,  OUTPUT);                                                               // For showing DCF-pulse with a LED
 pinMode(DCF_PIN,      INPUT_PULLUP);                                                         // Use Pin 2 for DCF input
 pinMode(DCFgood,      OUTPUT ); 
 pinMode(secondsPin,   OUTPUT );  
 pinMode(HeartbeatLED, OUTPUT );      
                          #ifdef MOD_DS3231
 RTCklok.begin();
 Tekstprintln("RTC DS3231 enabled");                                                          // Start the RTC-module
                          #else  
 RTCklok.begin(DateTime(F(__DATE__), F(__TIME__)));                                           // if no RTC module is installed use the ATMEGAchip clock
 Tekstprintln("Internal clock enabled");   
                          #endif //MOD_DS3231 
                          #ifdef BLUETOOTHMOD 
                          #if defined(ARDUINO_SAMD_MKRWIFI1010)
 Serial1.begin(9600);                                                                         // Bluetooth connected to Serial1
                          #else 
 Bluetooth.begin(9600);  
                          #endif //ARDUINO_SAMD_MKRWIFI1010
 Tekstprintln("Bluetooth enabled");
                          #endif //BLUETOOTHMOD
                          #ifdef ROTARYMOD   
 pinMode(encoderPinA,  INPUT_PULLUP);
 pinMode(encoderPinB,  INPUT_PULLUP);  
 pinMode(clearButton,  INPUT_PULLUP); 
 Tekstprintln("Rotary enabled"); 
 myEnc.write(0);                                                                              // Clear Rotary encode buffer
                          #endif //ROTARYMOD 
 strip.begin();
 strip.setBrightness(BRIGHTNESS); //BRIGHTNESS);
 ShowLeds();                                                                                  // Initialize all pixels to 'off' 
                          #ifdef LED6812    
 Tekstprintln("LEDs SK6812 enabled");
                          #endif //LED6812  
                          #ifdef LED2812
 Tekstprintln("LEDs WS2812 enabled");
                          #endif //LED2812 
                          #ifdef HC12MOD
 HC12.begin(9600);               // Serial port to HC12
 Tekstprintln("HC-12 time receiver enabled");
                          #endif //HC12MOD                           
                          #ifdef DCFMOD
 DCF.Start();                                                                                 // Start the DCF-module
 Tekstprintln("DCF77 enabled");
                          #endif  //DCFMOD
                          #ifdef DCFNOINT
 DCFmsTick = millis();
 Tekstprintln("DCFNOINT enabled");
                          #endif  //DCFNOINT
                          #ifdef LCDMOD
 lcd.begin (16,2); // for 16 x 2 LCD module                                                   // Activate LCD module
 lcd.setBacklightPin(3,POSITIVE);
 lcd.setBacklight(HIGH);
 Tekstprintln("LCD enabled");
                          #endif //LCDMOD
                          #if defined(ARDUINO_SAMD_MKRWIFI1010)
 Tekstprintln("MKR-1010 WIFI starting");
 Setup_MKRWIFI1010();                                                                         // Start the MKR1010
 Tekstprintln("MKR-1010 WIFI enabled");
                          #endif //ARDUINO_SAMD_MKRWIFI1010
                          #ifdef ARDUINO_AVR_NANO_EVERY
 Tekstprintln("Compiled for ARDUINO AVR NANO EVERY");
                          #endif
                          #if defined(__AVR_ATmega328P__) 
 Tekstprintln("Compiled for ARDUINO AVR ATmega328P");
                          #endif
                          #ifdef ATmega644_1284
 Tekstprintln("Compiled for ARDUINO AVR ATmega644_1284");
                          #endif
 DateTime now = RTCklok.now();
 DateTime compiled = DateTime(__DATE__, __TIME__);
 if (now.unixtime() < compiled.unixtime()) 
  {
   Serial.println(F("RTC is older than compile time! Updating"));                             // Following line sets the RTC to the date & time this sketch was compiled
   RTCklok.adjust(DateTime(F(__DATE__), F(__TIME__))); 
  }
 EEPROM.get(0,Mem);                                                                           // Get the data from EEPROM
 Mem.LightReducer    = constrain(Mem.LightReducer,1,250);                                     // 
 Mem.LowerBrightness = constrain(Mem.LowerBrightness,0,250);                                  // 
 Mem.DisplayChoice   = constrain(Mem.DisplayChoice,0,DIGITAL);                                // 
 if ( Mem.OwnColour == 0 ) Mem.OwnColour = 0X002345DD;                                        // If memory is empty then store default value, blue  
 EEPROM.put(0,Mem);                                                                           // update EEPROM if some data are out of the constrains                                                        
 DS3231NVRAMRead(0,NVRAMmem);                                                                 // Read the LDR reading from NVRAM DS3231 clock module if present
 Previous_LDR_read = analogRead(PhotoCellPin);                                                // to have a start value
 MinPhotocell      = Previous_LDR_read;                                                       // Stores minimum reading of photocell;
 MaxPhotocell      = Previous_LDR_read;                                                       // Stores maximum reading of photocell;  
// Selftest();                                                                                // Play the selftest
 GetTijd(0);                                                                                  // Get the time and store it in the proper variables
 SWversion();                                                                                 // Display the version number of the software
 //Displaytime();
 SetColours();                                                                                // Set colours according chosen palette
 msTick = Looptime = millis();                                                                // Used in KY-040 rotary for debouncing and seconds check 
 }
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

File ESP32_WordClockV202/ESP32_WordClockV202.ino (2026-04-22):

/* 
 Author      : Ed Nieuwenhuys ednieuw.nl
 Changes V001: Derived from ESP32C3S3_WordClockV026.ino
 Changes V003: Clock and SK6812 LEDstrip working
...
 Changes V094: Replaced NIMBLE with ESP32 BLE
...
 Changes V130: Removed old coding and use NEOPIXEL and use ESPAsyncWebServer. 203222 l/s again instead of 140000
 Changes V131: Added H04 tiny IR-remote
 Changes V132: Cleanup code
 Changes V133: Added in CheckRestoreWIFIconnectivity() Failsafe NoConnectionCounter that restart after 30 minutes no IP when WIFI is On 
 Changes V134: Added in CheckRestoreWIFIconnectivity() Loopcounter<10 and network available. --> Will reboot. Minor typos and cleanups
 Changes V135: Optimized used of CheckRestoreWIFIconnectivity() and check every hour instead of every mniute
 Changes V136: Added Log viewer webpage url/log 
 Changes V137: No use
 Changes V138: Solve restart ESP32 sprintf --> snprintf
 Changes V139: Logviewer -> 500 lines
 Changes V140: Changed wifi case WL_CONNECTED:
 Changes V141: Ringbuffer with String and Free heap is working OK
 Changes V142: Ringbuffer to char** 
 Changes V143: Ringbuffer to char** optimized
 Changes V144: Keeps all logs in PSRAM  Limits /tekstprint to 500 lines for safe browser display  Allows /tekstdownload for full log retrieval
 Changes V145: No log file anymore --> solved while (!Serial && ( (millis()-Tick) < 500)) { delay(50); }
 Changes V146: Works OK
 Changes V147: Line numbers removed and code cleaning in Logviewer.h 
 Changes V148: Replace snprintf(sptext, sizeof(sptext) with Tekstprintf. Added Option Y { and G from web page menu not possible
 Changes V149: Flashing warning text Option Y or G not possible in web page menu. Optimized bool GetNTPtime(bool printit) . Mem.TimeLogPrint used to turn off time printing every minute
               Major cleanup and bugfixes
 Changes V150: Stable version
 Changes V151: functie FILENAAM \ ook voor MacOS/Linux /.  Mem.TimeLogPrint       = 1;    // Print time per minute (1) or hour (2)
 Changes V152: error in 4-L clock solved. Optimized print time /min /hr
 Changes V153: Larger ringbuffer
 Changes V154: Optimizing K0 K1 K2
 Changes V155: No menu print to logging when SWversion is printed to Webpage. Added DoNotLog flag
 Changes V156: Optimize use of DoNotLog flag. const char* PrintRTCTime() --> Tekstprintln(PrintRTCTime()); WTekstprint(PrintRTCTime(), "<!--", " -->");
 Changes V157: testing
 Changes V158: K0 not updating LEDs.-->fixed. added in Everyminute() 
 Changes V159: Double printing of menu in Logging solved. Option K2 solved extra printing
 Changes V160: Stable
 Changes V161 - V173 BLEtimeSender code development Changes V185: Changed name of TimeSender -> TimeReceiver.
 Changes V174: Time sender working 
 Changes V175: ToDo: Make time sender optional with Mem.TimeSender. SendMessageBLE(string -> const char* msg)
 Changes V176: deviceConnected ->  BLEConnected TSConnected
 Changes V178: Ringbuffer 
 Changes V179: Ringbuffer 
 Changes V180: Ringbuffer repaired. BLE time Sender optimized. 
 Changes V181: Testing. Cleanup code
 Changes V182: Make use of timesender selectable
 Changes V183: Stable version
 Changes V184: Print of long logbuffer in chunks to avoid crash as txt download file
 Changes V185: Changed name of TimeSender -> TimeReceiver.
 Changes V186: Simplified: "attachment; filename=\"%s-log.txt\"", Mem.BLEbroadcastName);
 Changes V187: Added CheckWIFIcommand() to avoid WIFI crashes when a command take several seconds to end, like LEDtest()
 Changes V188: Stable
 Changes V189: Added DisconnectBLE() as function. When @ in webpage inputfield cleared from sticking @.
 Changes V190: Variables etc. renamed from Timesender -> Timereceiver in Timereceiver functions   
 Changes V191: In timereceiver Connected to: Mem.BLEbroadcastName and yellow status LED when connected
 Changes V192: Repair 4-language clock display. Renamed Playlights() --> LEDtest(). 
               Q8=RAINBOW resetting ESP32 solved to -> update per minute. After 5 MCU restart in an hout Reset all settings to factory default 
 Changes V193: Refined Mem.MCUrestarted. No ResetCredential. Set counter to 0 between 1 and 2 hours
 Changes V194: Refined logging (NTP update and time send when LEDs turn on/off with n2208) Mem.TimeMinute --> MemTimeLogPrint
 Changes V195: Cleanup code. Comparable with ESP32Arduino_CommV022.ino. Corrected bug ->  Mem.NVRAMmem[lasthour] = NoofLDRreadshour ? (byte)(SumLDRreadshour / NoofLDRreadshour) : 0;
 Changes V196: To avoid translation lang="en" added -> <html lang="en"><head>. Changes in void PrintMem(void) .
 Changes V197: Added menu option V: Background colour not used LEDs (to hide bleeding between LED cells) 
 Changes V198: Viertalenklok Ulrich added  #define VIERTALENKLOK
 Changes V199: All Rework in Webpage to CheckWIFIcommand(). 199a Clock logic in ClockLogic.h. Corrected double Menu i and ii on webpage when BLE open.
               Updated HTML and logging behaviour. Added option V background, Changed LDR reading when background is on, input decimal or hexadecimal, KURZ, EXACT etc bij Ulrich 4-talen weg
               Removed short LDR reading under X LDR_LED. NoTextInLeds in EveryHourUpdate -> end of function 
               lastminute = 99; -> end ReworkInputString .Cleanup code. 
 Changes V200: OTA logic improved
 Changes V201: LED near LDR on/off 
 Changes V202: HET IS WAS can also OFF in FOURLANGUAGECLOCK and VIERTALENKLOK

 Issue: Long menu still does not print properly in IOS Timesender app.
*********************
How to compile: 
Install ESP32 boards
Board: ESP32 core version >3.2.0 
Partition Scheme: With FAT
Pin Numbering: By Arduino pin (default)     -- > with EdsoftLED both can be used
               By GPIO number (legacy)      -- > When using NEOpixel
               Adafruit_NeoPixel/esp.c:78:(.text.espShow+0x55): undefined reference to `digitalPinToGPIONumber' when using By Arduino pin
USB mode: Normal (Tiny USB)
**********************

Select below, with only one #define selected, the clock type

*/
// =============================================================================================================================
// ------------------>   Define only one clock type
//#define NL144CLOCK              // Dutch display for 12 x 12 Front
#define FOURLANGUAGECLOCK       // Four-language clock with 625 LEDs 
//#define NL92CLOCK               // Dutch display for one LED behind every character
//#define NLM1M2M3M4L161          // NL EdSoft Qclock design
//#define DE144CLOCK              // German display for 12 x 12 Front
//#define NLM1M2M3M4L94           // NL clock with four extra LEDs for the minutes to light up 
//#define NLM1M2M3M4L114          // NL clock with four extra LEDs for the minutes to light up
//#define NLM1M2M3M4L144          // NL clock with four extra LEDs for the minutes to light up 
//#define NLM1M2M3M4L256          // NL clock with four extra LEDs for the minutes to light up
//#define VIERTALENKLOK           // Viertalenklok Ulrich
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

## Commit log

2023-02-13 Fritzing PCB V16
    Fritzing file for RGB(w) strip and Arduino Nano and Nano Every boards
    [Colour Word Clock PCBV16.fzz]
2023-02-13 Colour Word Clock PCBV16.fzz
2026-04-22 V202
    For Arduino Nano ESP32
2026-04-22 Update README with ESP32 support and manual link
    Added update note for Arduino Nano ESP32 and link to manual.
